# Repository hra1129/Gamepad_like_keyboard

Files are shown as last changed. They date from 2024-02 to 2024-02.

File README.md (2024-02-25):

# Gamepad_like_keyboard
 キーボードのようなMSX用・SORD M5用ゲームパッド

デフォルトでは、MSX用になっています。
M5用にするためには、MSX Mode と書かれているジャンパをカットして、M5 Mode と書かれているジャンパをショートさせます。
さらに、６つのダイオードを取り付ける必要があります。

キースイッチは、こちら。
https://shop.yushakobo.jp/products/pg1350?_pos=31&_fid=22e06b805&_ss=c

キーキャップは、こちら。
https://shop.yushakobo.jp/products/mbk-choc-low-profile-keycaps?_pos=2&_sid=e73e42cb9&_ss=r

MSX用にする場合は、9pin AMPケーブルを用意して下さい。
M5用にする場合は、PS/2キーボード延長ケーブルやPS/2分岐ケーブルなどを使うのが良いです。（PS/2キーボードやマウスのケーブルは線が省略されている場合があり､その場合使えません）

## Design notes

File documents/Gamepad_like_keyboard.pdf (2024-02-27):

# Gamepad for MSX/M5

Rev.1 の基板は、MSX用としてのみ利用可能です。
Rev.2 の基板は、MSX用/SORD M5用を基板上の設定で切り替えられます(※まだ未確認)。

基板の他に用意するモノ

基板の他に用意するモノ
・Kailh Choe v1 ロープロファイルスイッチ ６個 https://shop.yushakobo.jp/products/pg1350?_pos=31&_fid=22e06b805&_ss=c
・Kailh Choe v1用キーキャップ 6個
https://shop.yushakobo.jp/products/mbk-choc-low-profile-keycaps?_pos=2&_sid=e73e42cb9&_ss=r ・AMP 9pin ケーブル 1本
https://www.kadenken.com/view/item/000000000862
ヤフオクなどにも出てることがあります。

あった方が良いモノ
・結束バンド
AMP 9pin ケーブルを基板にくくりつけるために使います。 ・M3 15mm スペーサー と M3ネジ 6組
基板に付ける足になります。

## MSX用として組み立て (Rev.1/Rev.2 共通）

基板は、デフォルトで MSX用になっていますので、ボタンとケーブルを半田付けすれば完成です。
AMP 9pin ケーブルは、MSX Connector と書かれているところに取り付けて下さい。
AMP 9pin ケーブルは、モノによって内部の線材の被服の色が異なっているようなので、不明な場合はテスターなどで確認して、間違えないようにご注意下さい。

カスタマイズ
MSXのゲームパッドは、単純なスイッチになっていますので、配線を入れ替えるとキーの機能を入れ替えることが出来ます。
Aボタンと Bボタンを入れ替えたい → 6番と7番を入れ替える。
上下、左右を入れ替えて逆さまで使いたい → 1番と2番を入れ替え、3番と4番を入れ替える。

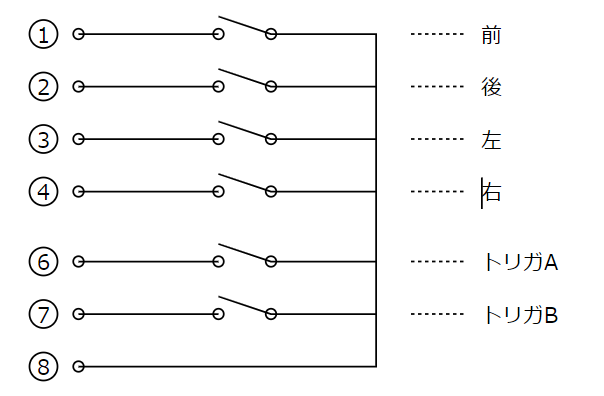
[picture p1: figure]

## SORD M5用として組み立て (Rev.2 のみ）

MSX Mode と書かれているJPをカッターナイフなどでカットして下さい。
M5 Mode と書かれているJPを半田を盛るなどして接続して下さい。 六カ所のダイオードのマークのところに、ダイオードを取り付けて下さい。 PS/2キーボード延長ケーブルなどのオス側を M5 Connector のところに半田付けしてください。

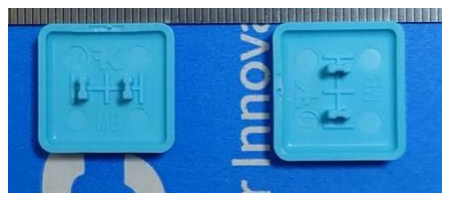
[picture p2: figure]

Kailh ロープロファイルスイッチ | Kailh 用キーキャップ

# Github https://github.com/hra1129/Gamepad_like_keyboard

[注意]

## 配線を間違えると、MSX/M5本体を壊す恐れがあります。 この基板を使用して、何らかの損害が発生しても責任を負いかねます。 ご自身の責任でご利用下さい。

9

5 | 4 | 3 | 2 | 1
8 | 7 | 6
MSXジョイスティックケーブ
ルの穴のピンアサイン

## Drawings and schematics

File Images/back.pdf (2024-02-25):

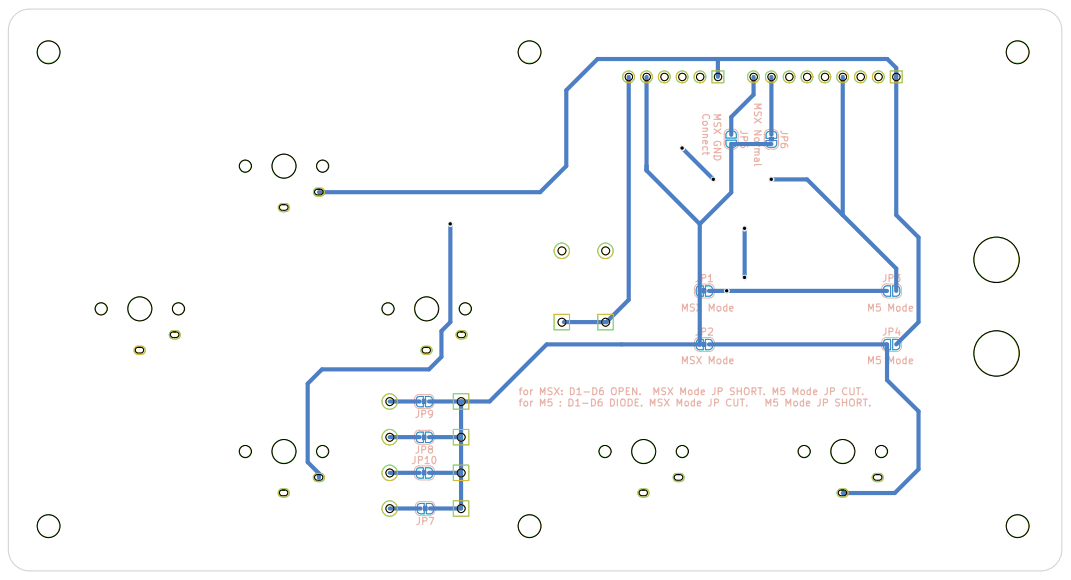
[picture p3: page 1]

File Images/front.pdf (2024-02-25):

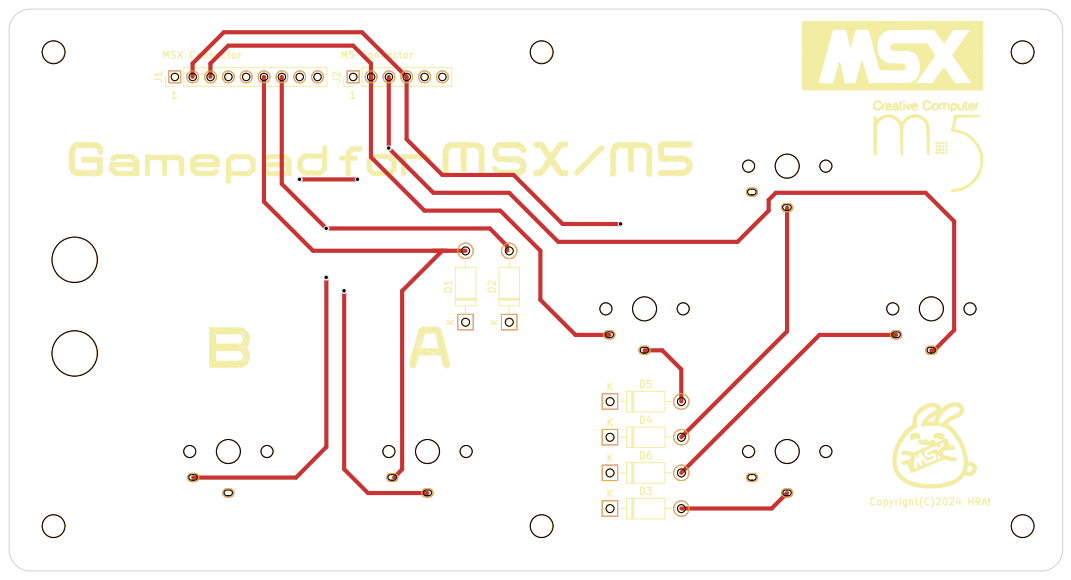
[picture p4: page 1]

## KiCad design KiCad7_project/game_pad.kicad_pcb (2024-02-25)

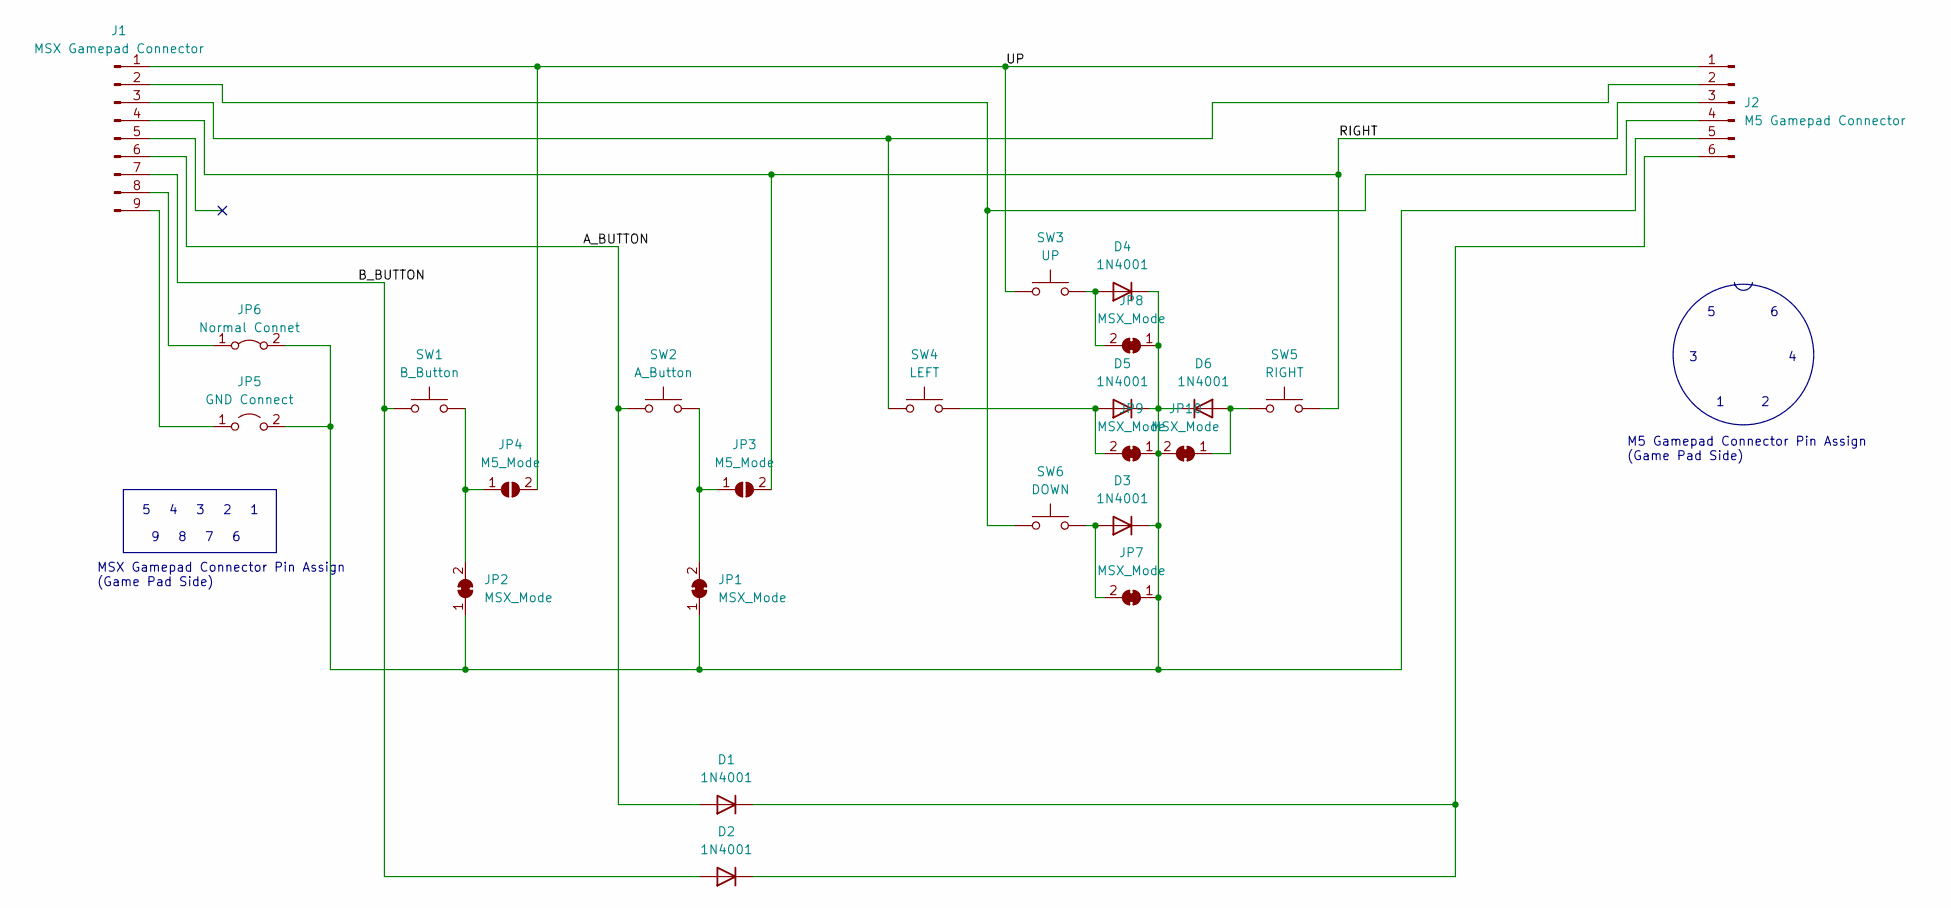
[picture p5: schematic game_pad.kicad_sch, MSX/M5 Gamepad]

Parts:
D1, D2, D3, D4, D5, D6: 1N4001; D_DO-41_SOD81_P10.16mm_Horizontal
J1: MSX Gamepad Connector; PinHeader_1x09_P2.54mm_Vertical
J2: M5 Gamepad Connector; PinHeader_1x06_P2.54mm_Vertical
JP1, JP2, JP7, JP8, JP9, JP10: MSX_Mode; SolderJumper-2_P1.3mm_Bridged_RoundedPad1.0x1.5mm
JP3, JP4: M5_Mode; SolderJumper-2_P1.3mm_Open_RoundedPad1.0x1.5mm
JP5: GND Connect; SolderJumper-2_P1.3mm_Open_RoundedPad1.0x1.5mm
JP6: Normal Connet; SolderJumper-2_P1.3mm_Bridged_RoundedPad1.0x1.5mm
SW1: B_Button; Kailh_Choc_V1
SW2: A_Button; Kailh_Choc_V1
SW3: UP; Kailh_Choc_V1
SW4: LEFT; Kailh_Choc_V1
SW5: RIGHT; Kailh_Choc_V1
SW6: DOWN; Kailh_Choc_V1

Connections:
/A_BUTTON: D1.2 (A), J1.6, SW2.1
/B_BUTTON: D2.2 (A), J1.7, SW1.1
/RIGHT: J1.4, J2.3, JP3.2 (B), SW5.2
/UP: J1.1, J2.1, JP4.2 (B), SW3.1
unnamed: D1.1 (K), D2.1 (K), J2.6
unnamed: D3.2 (A), JP7.2 (B), SW6.2
unnamed: D3.1 (K), D4.1 (K), D5.1 (K), D6.1 (K), J2.5, JP1.1 (A), JP2.1 (A), JP5.2 (B), JP6.2 (B), JP7.1 (A), JP8.1 (A), JP9.1 (A), JP10.2 (B)
unnamed: D4.2 (A), JP8.2 (B), SW3.2
unnamed: D5.2 (A), JP9.2 (B), SW4.2
unnamed: D6.2 (A), JP10.1 (A), SW5.1
unnamed: J1.2, J2.4, SW6.1
unnamed: J1.3, J2.2, SW4.1
unnamed: J1.8, JP6.1 (A)
unnamed: J1.9, JP5.1 (A)
unnamed: JP1.2 (B), JP3.1 (A), SW2.2
unnamed: JP2.2 (B), JP4.1 (A), SW1.2

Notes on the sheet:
M5 Gamepad Connector Pin Assign (Game Pad Side)
MSX Gamepad Connector Pin Assign (Game Pad Side)

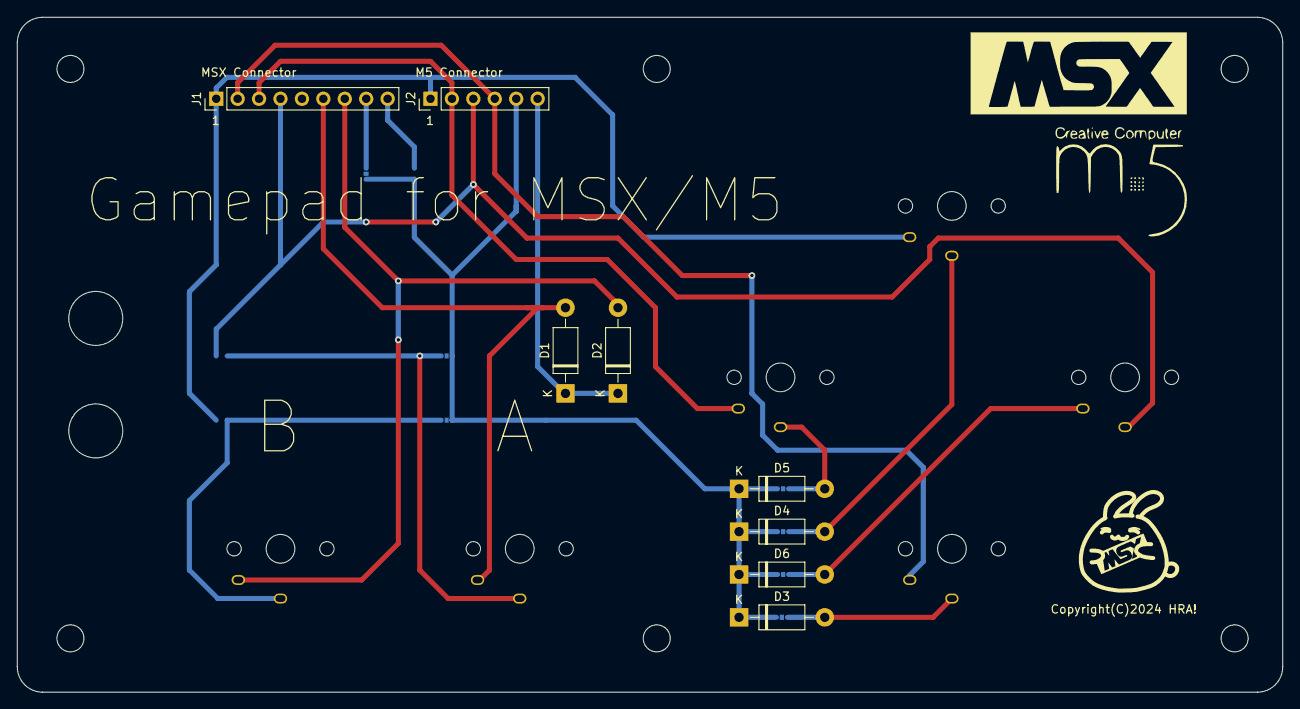
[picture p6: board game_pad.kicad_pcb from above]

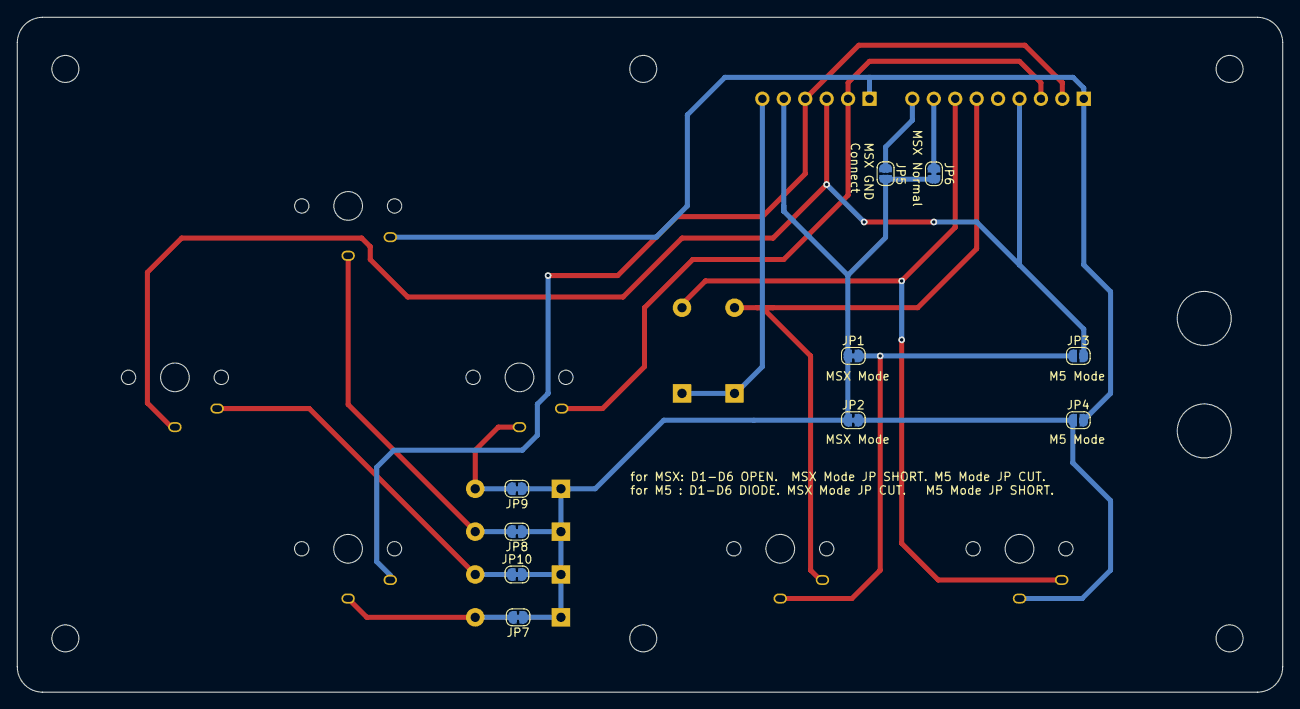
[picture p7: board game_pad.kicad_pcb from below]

Board: 2 copper layers, 150.0 x 80.0 mm, 32 parts (10 on the bottom side), 16 nets.

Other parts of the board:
HOLE1, HOLE2: (no value)
MH1, MH2, MH3, MH3#2, MH3#3, MH4: MountingHole_3.2mm_M3

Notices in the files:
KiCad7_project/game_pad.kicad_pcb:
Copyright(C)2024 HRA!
